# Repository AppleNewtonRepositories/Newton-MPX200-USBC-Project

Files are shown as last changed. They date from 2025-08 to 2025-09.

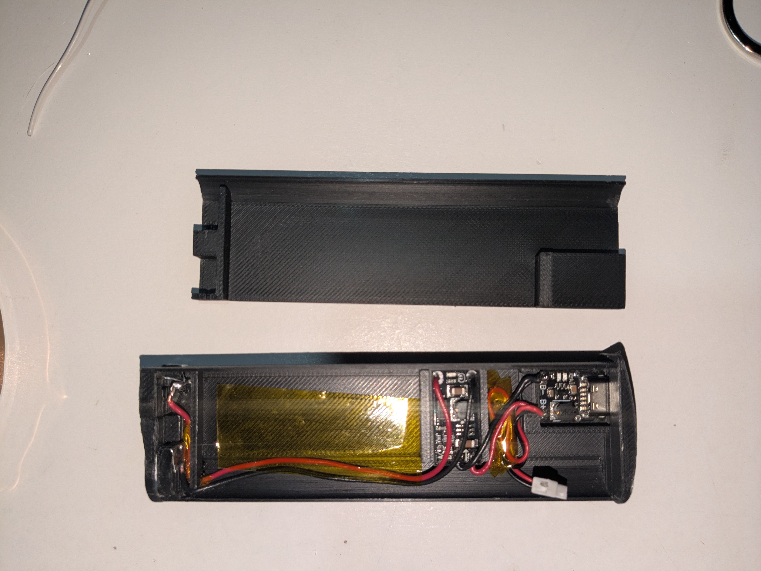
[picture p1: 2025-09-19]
Research/Battery with Wiring Before Cell Added V4.jpg

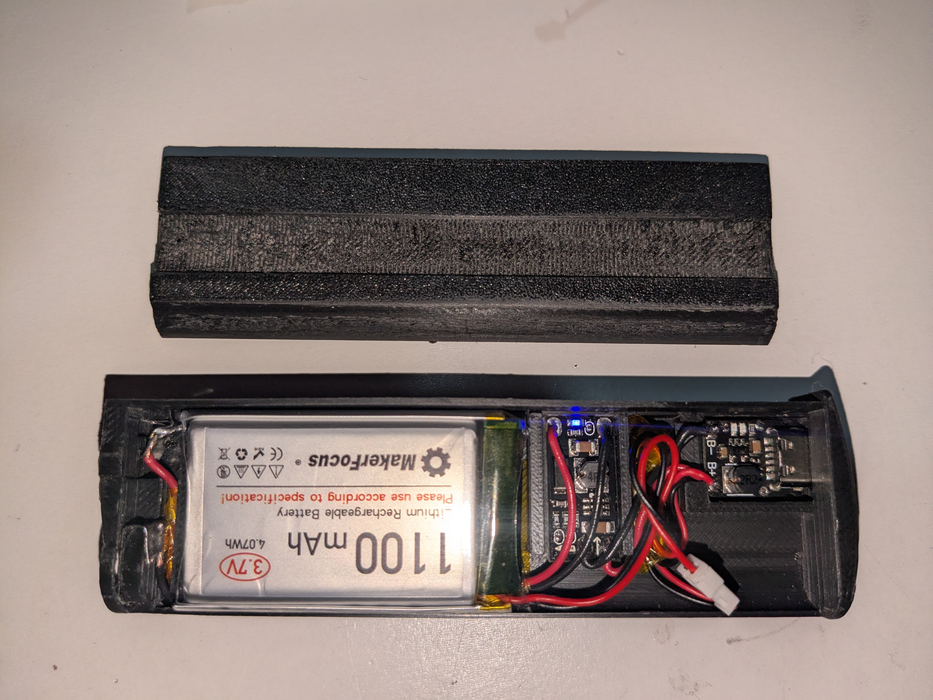
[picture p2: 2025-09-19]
Research/Completed Battery with Cell V4.jpg

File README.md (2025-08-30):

# Newton-MPX200-USBC-Project
A project to utilize a new 3d Printed Holder and additional electronics to enable USB-C on the apple newton Messagepad 2x00 Series

This is mostly a repository of available research and data to support the project.

Original Source for the Battery Model is at https://github.com/niterain/Newton-MP2x00-AA-Battery-Tray/tree/master

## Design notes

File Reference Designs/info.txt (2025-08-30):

This is a folder for reeference designs

The Newton messagepad-2x00 aa battery tray file is printed standing on the bottom with the pull tab facing up when slicing and has been tested in an MP2000 and 2100.

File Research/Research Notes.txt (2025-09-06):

Research Notes:

None of this information has been tested at this point!  This is for reference only!  

I AM NOT RESPONSIBLE FOR ITS USE!

Batteries:
There are many batteries available that could be used, focussing on Lithium ION is the main goal for availability, stability, and new chemistry.
1) Pouch Cells - Pouch cells must be able to fit inside of the modified tray.  They are known to catastrophically fail, but are technologies that are used in almost all small devices such as smartphones.  They support a high charge and discharge rate and are readily available.

2) Enclosed Cells - There are many cells available in a closed cell that could be used but only the AA (14500) and AAA (10440) sizes will work, we must limit to two cells in order to make room in the tray for the charging boards.

Charging Boards:
There are quite a few charging boards available off the shelf that will fit the application.  So far I am investigating the below from Amazon:
This one is Yet untested but the newton draws less than 100ma so it will not power the clock when idle
https://www.amazon.com/dp/B09YD5C9QC/

This one has been tested, however when the USB is switched from charge to power and back there is a 1-2 second delay in switch which interrupts the power for the battery.  I am looking at adding an intelligent boost board that will allow power with a cutoff for dead batteries that can work along side this.
https://www.amazon.com/dp/B0D7Z92K51/

If we go to NIMH AAA cells and use USBC with those we can use this board:
https://www.amazon.com/dp/B0D6BDFXLH/

Boost Converter:
I have been toying around with the idea of a boost converter that can be used to USB-C charge the newton externally from any power supply.

This would require two components, one to get the power from USB-C and one to get the power to the newton and regulate current and voltage to a respectible voltage.

Boost Converter https://www.amazon.com/Converter-2-6-5-5-Step-up-Voltage-Regulator/dp/B084Z3CS3M/

Module to get USB-C at 1A for the boost converter:
Set for 5V Output!!!!  Verify everything with a volt meter!!!
https://www.amazon.com/ACEIRMC-Trigger-Polling-Detector-Notebook/dp/B0BTHXKM91/

Tips that should fit a newton:
https://www.amazon.com/uxcell-4-8x1-7mm-Solderless-Connectors-Replacement/dp/B07F68VWZY

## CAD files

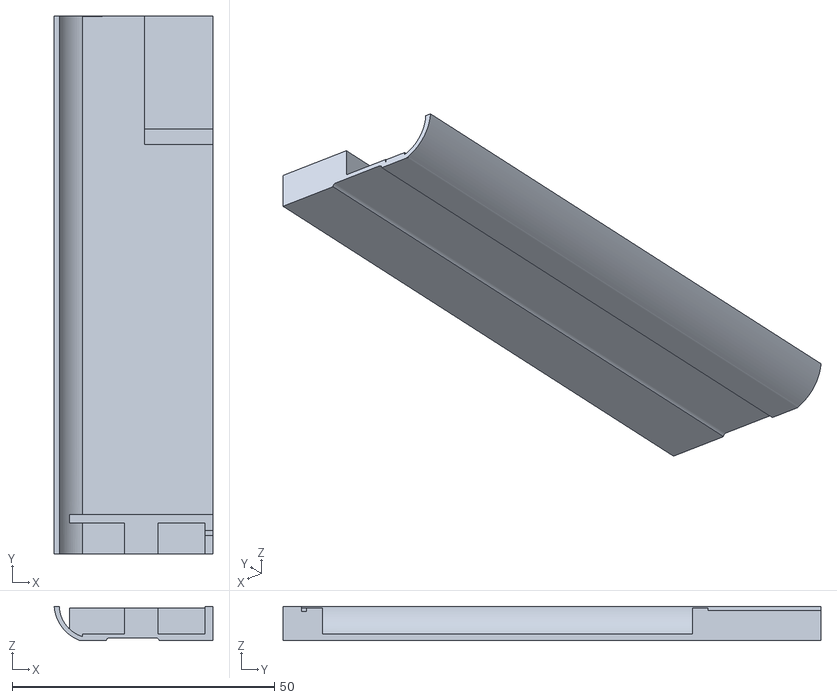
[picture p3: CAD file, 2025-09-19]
3d Printing Files/Battery V5 New Board Top.stl
30.2 x 102.5 x 6.50

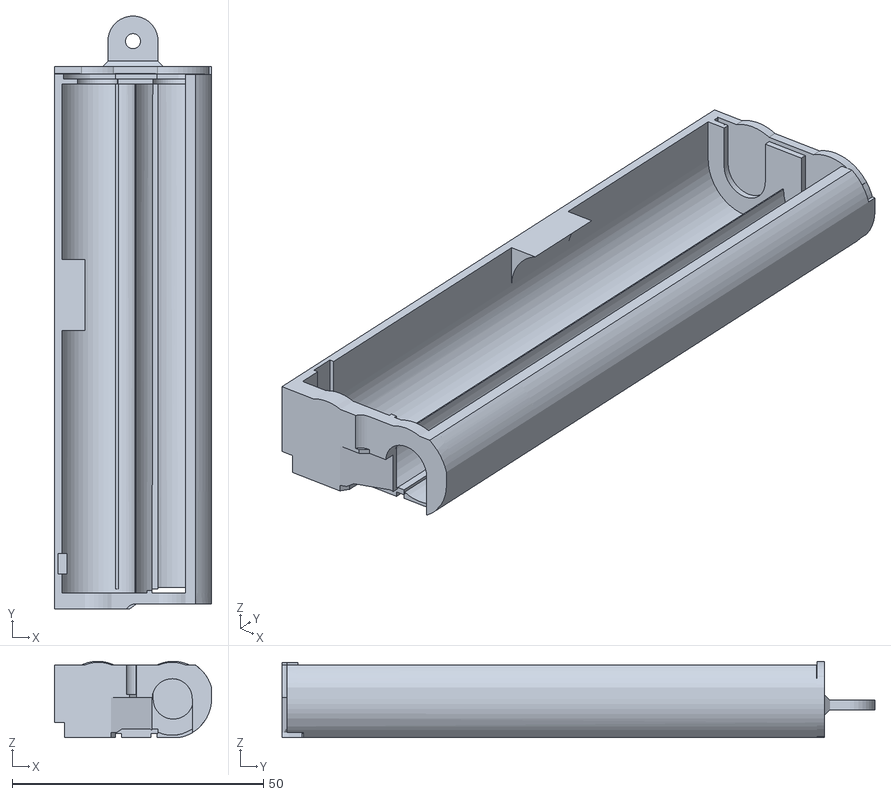
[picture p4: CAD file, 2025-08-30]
Reference Designs/newton-messagepad-2x00-aa-battery-tray-alt-Modded.stl
31.3 x 118.0 x 15.2

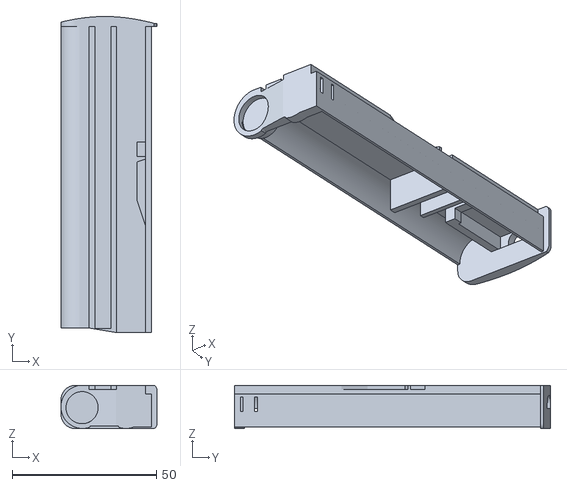
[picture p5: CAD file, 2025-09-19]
3d Printing Files/Battery V5 New Board Bottom.stl
33.3 x 109.4 x 15.0

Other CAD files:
3d Printing Files/Battery Top V4_1.stl
3d Printing Files/Battery Bottom V4_1.stl

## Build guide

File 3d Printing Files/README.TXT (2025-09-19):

VERIFY VOLTAGES OF BOOST BOARD BEFORE INSTALLING!! THEY DEFAULT TO 12V!!!  REMOVE ALL JUMPERS!!!  EVEN THE LED JUMPER!!!  UNLESS NEEDED FOR TESTING!!!  VERIFY YOUR OUTPUT AT THE TERMINALS IS 5VDC!!!
This directory contains the 3d Printing files for prototype batteries,  these are all works in progress, your mileage may vary.

Version 4.0 - First prototype version incorporating a BOOST converter and Charge Controller module.  Modules will be listed in the assembly instructions which will be released as the system is built.

Version 4.0 Notes - 3D Printed 4 revisions, 4th revision modified to fit properly and is in testing as a two half design.  This is designed to fit flattest sides down on the print bed for both top and bottom covers.
ALL Boost Boards must be configured as such: 5V - NO LED (Remove all jumpers)
VERIFY VOLTAGES OF BOOST BOARD BEFORE INSTALLING!! THEY DEFAULT TO 12V!!!  REMOVE ALL JUMPERS!!!  EVEN THE LED JUMPER!!!  UNLESS NEEDED FOR TESTING!!!  VERIFY YOUR OUTPUT AT THE TERMINALS IS 5VDC!!!

Version 4 parts:
USBC Charge board:
https://www.amazon.com/dp/B0D7Z92K51

BOOST Converter:
https://www.amazon.com/dp/B09D3G96KZ

Battery:
https://www.amazon.com/dp/B0867KDMY7
OR For a better fit:
https://www.amazon.com/dp/B0F9YSFV4T

Version 5.0 Notes - Changes made to charge board to reduce current draw.
ALL Boost Boards must be configured as such: 5V - NO LED (Remove all jumpers)

***********VERSION 5.0***************
Version 5.0 - Changes to support the larger charging/protection board which has no boost converter

Version 5 Parts:
USBC Charge Board TP4057 Board:
https://www.amazon.com/dp/B0DG1XP27Y

BOOST Converter:
https://www.amazon.com/dp/B09D3G96KZ

Battery:
https://www.amazon.com/dp/B0867KDMY7
OR For a better fit:
https://www.amazon.com/dp/B0F9YSFV4T

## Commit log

2025-08-30 Add files via upload
    Original MP2x00 design from niterain github at https://github.com/niterain/Newton-MP2x00-AA-Battery-Tray/tree/master with modifications to allow it to print solid on a 0.4mm nozzle. This is a Work in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
    [newton-messagepad-2x00-aa-battery-tray-alt-Modded.stl]
2025-08-30 Add files via upload
    Modified version of https://github.com/niterain/Newton-MP2x00-AA-Battery-Tray/tree/master battery holder to support a 0.4 mm nozzle
    [newton-messagepad-2x00-aa-battery-tray-alt-Modded.stl]
2025-08-30 Create Research Notes.txt
    Research notes on batteries and charger boards added.
2025-08-30 Update README.md
    added source for battery STL Model
2025-08-31 Update Research Notes.txt
    added power adaptor information to research notes.
2025-09-06 Update Research Notes.txt
    Added notes about USB Power/Charge board testing.
2025-09-14 Create README.TXT
    Added 3D Printing Files Readme
2025-09-14 Version 4 3d Printing version
    Version 4 two halves printed with no supports in testing 14 September 2025
    [Bottom Half Battery V4.stl, Top Half Battery V4.stl]
2025-09-14 Connection Diagram for boards
    Connection Diagram for BOOST and Charge Boards.
2025-09-14 Delete 3d Printing Files/Top Half Battery V4.stl
    Deleted due to fitment issues replaced with v 4_1
    [Top Half Battery V4.stl]
2025-09-14 Newer files with better fitment for battery tray
    Newer files with better fitment for battery tray
    [Battery Bottom V4_1.stl, Battery Top V4_1.stl]
2025-09-19 Update README.TXT
    Added updates to support new boards.
2025-09-19 Pictures of Construction Process of Battery
    Construction pictures of battery
2025-09-19 V5 Prototype Added
    V5 Prototype Added
    [Battery V5 New Board Bottom.stl, Battery V5 New Board Top.stl]
